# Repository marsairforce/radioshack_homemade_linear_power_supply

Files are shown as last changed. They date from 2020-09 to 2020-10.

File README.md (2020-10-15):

# Vintage Adjustable Linear Power Supply

Updating and improving on a very early project I built.

* Partly because I want something to do more things - dual tracking adjustable regulated outputs.
* Partly because I wanted to see how far I have come in my design skills from 10 year old me.
* Partly because I am bored

 I have been wanting to get more into analog circuits, like op-amp circuits and amplifiers. Building these on breadboards has always been challenging for me because I have always had only one bench power supply.  I have a modern bench power supply, but it also only has one output on it.

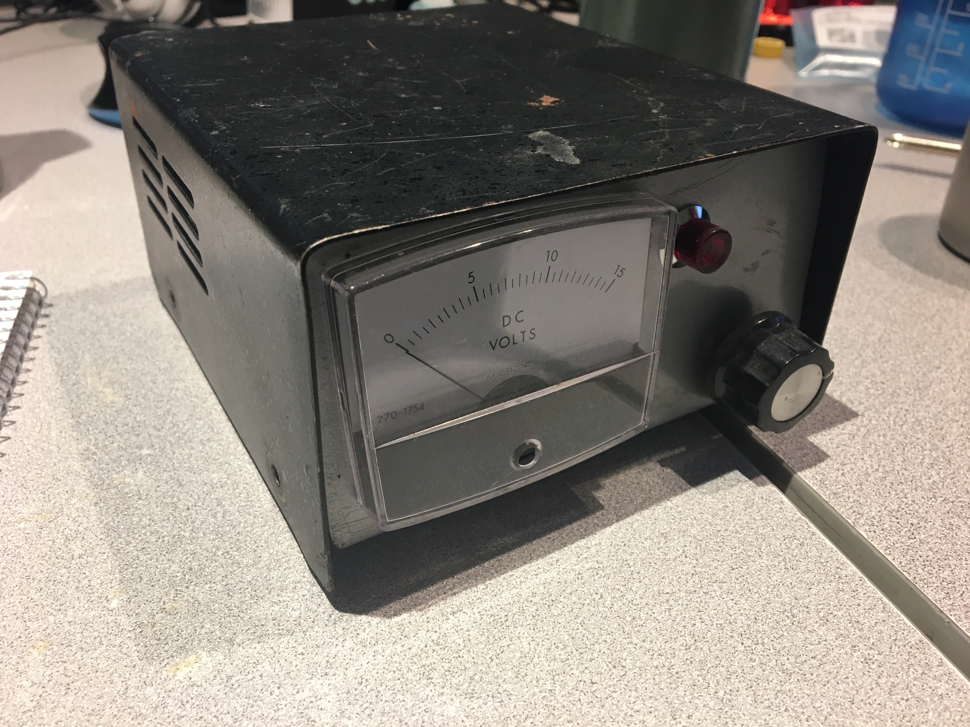
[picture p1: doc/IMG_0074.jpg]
old version together


## TL;DR

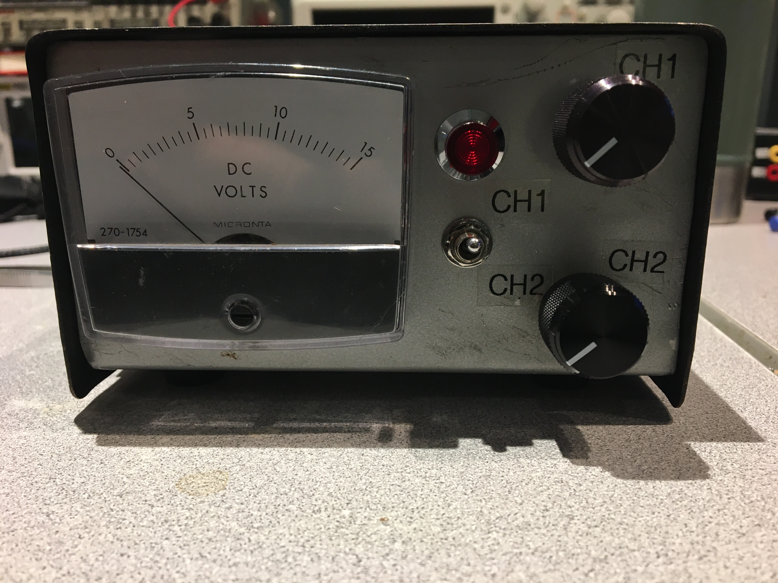
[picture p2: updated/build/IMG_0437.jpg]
front assembled


This is now a dual channel, double trackking voltage power supply.

Each channel can do about +/-1.2V to +/-20V at about 1A

## Analysis

I created this (I think) when I was in grade 4. So probably around 1987?

* Simple 317 regulator based adjustable power supply.

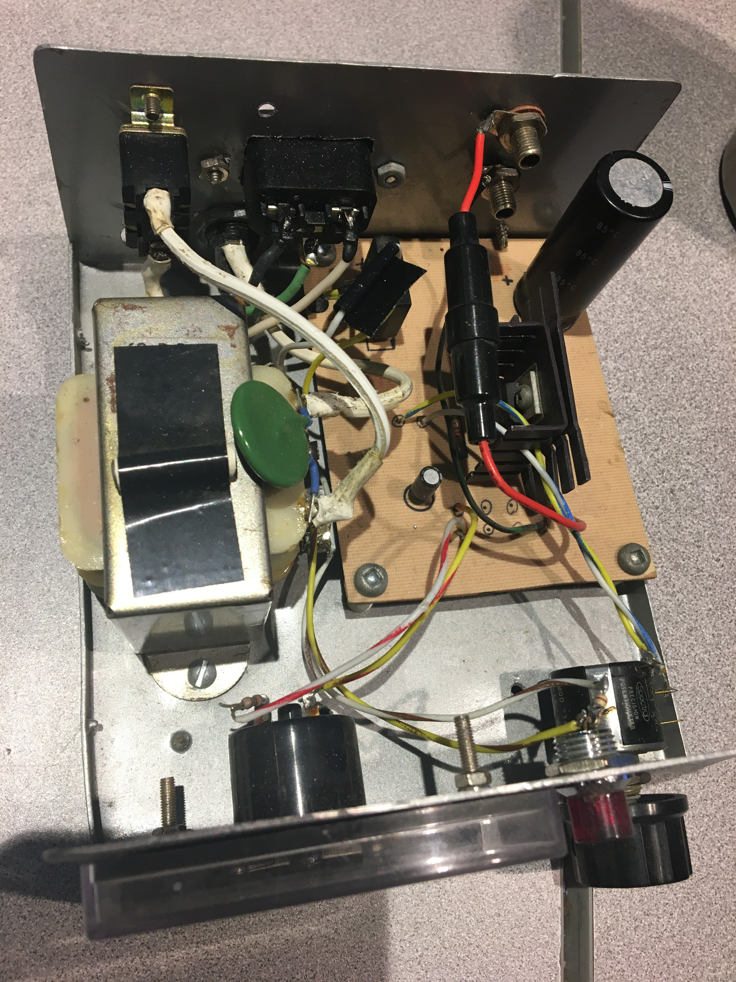
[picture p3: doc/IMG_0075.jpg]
inside


* Most components were baught from local Radio Shack store in St Vital mall.

  * Radio Shack project box.
  * 18V CT, 2A (36VA?) transformer.
  * Bridge Rectifier.
  * 2200uF capacitor
  * 317 volt regulator on free hanging heatsink.
  * Basic power connector, switch, fuze, with shitty heat shrink tubing on it.
  * Analog DC volt meter.
  * Indicator lamp, but bulb burnt out so I replaced it at some time with a LED stuffed into the lamp holder.
  * A pointless inline fuse holder, with a 2A fuse. This never would blow because the thing can only source 1A
  * Adjustable voltage knob - I remember getting this multi turn potentiometer from Active Electronics.
  * Custom etched single sided PCB
  * Serrible banana plug jacks.
  * Board standoffs (Active Electronics - I still have these) with stove bolts from hardware store.

I would like to say "I have come a long way since then". But at the same time, not really.

* I don't have a convenient way to make circuit boards at home any more.

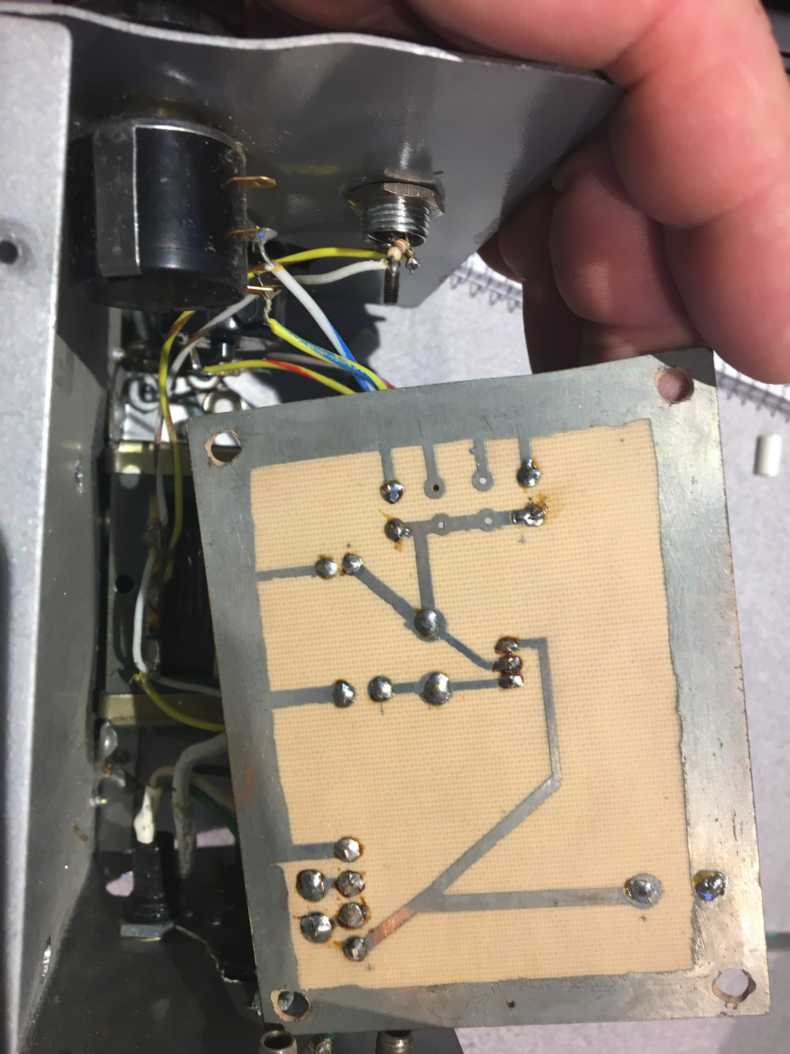
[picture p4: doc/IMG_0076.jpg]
pcb


This gem was hand drawn with a sharpie and then using a liquid tin to protect the copper.

In hindsight this is a terrible board layout.

* I still do not have good nuts and bolts hardware to mount circuit boards.

I have learned or improved a little bit more since I built this:

* I do have much better selection of wires now.

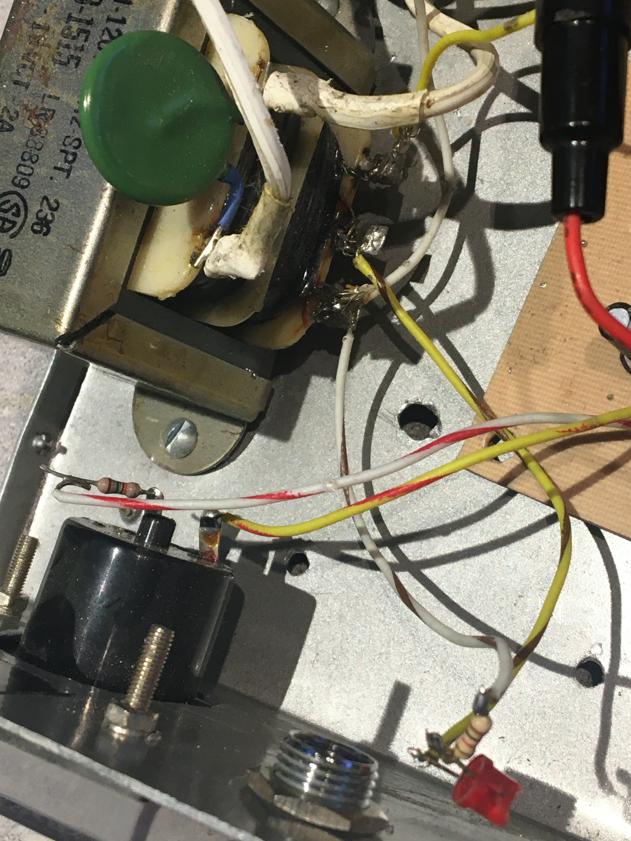
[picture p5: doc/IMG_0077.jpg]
old wires


* My soldering skills are a lot better. This thing looks like a Halloween house of horrors.

## Original Schematic

I created this in Kicad

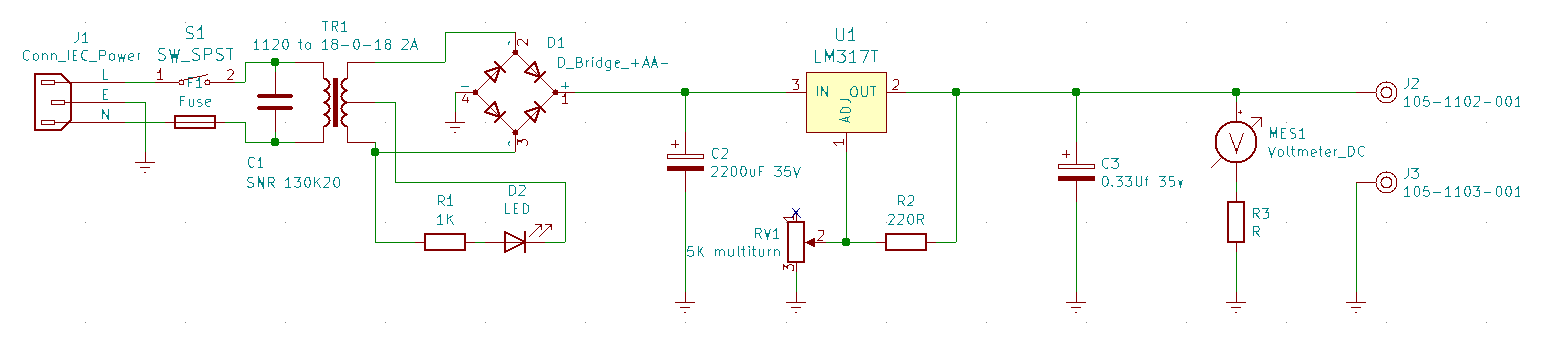
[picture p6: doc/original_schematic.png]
original schematic


This still functioned very well.

Funny notes as I was taking the old circuit apart.

* The C1 makes no sense. Why did I think I needed to have a ac line capacitor here? I probably had these and copied what I saw in other power supplies.
* The F1 should be after the switch on the hot side.
* The wires from J1, S1, T1 were a white lamp cord. I remember having this and using it for everything.
* The wires from T1 to the circuit board and everywhere else were from an old datacom cable I salvaged from one of my dad's construction sites. I stripped the cable jacket and used the wires for projects.
* I made a PCB using the kit from RadioShack. It is horrible layout and terrible pattern. But I did it with a sharpie and I was 8.
* The J2 was a metal not insulated binding post. As a kid I converted it into an insulated binding post by placing a piece of plastic drinking straw around the metal screw part of the  between the connector and the chassis. Somehow it continued to work all these years.

## Improvements

As usual I can't leave anything alone. Nothing is ever truly completed is it.

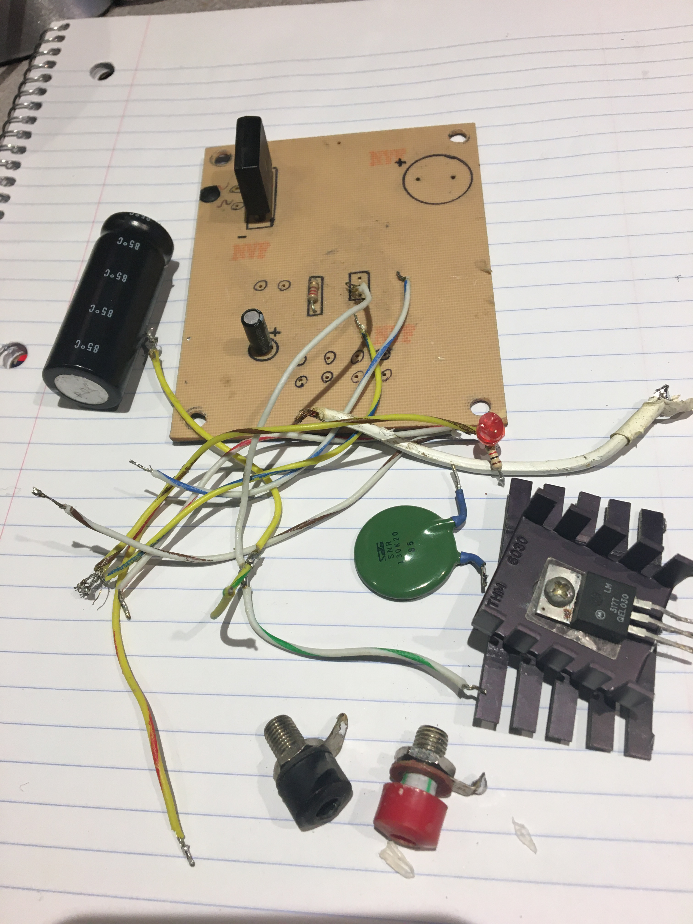
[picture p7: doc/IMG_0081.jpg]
taken apart


I ripped apart the old circuit and removed the parts from the chassis.  The front panel and bottom was a bit bent up from this being knocked around in storage I guess.

### Support more current output

* [Researching](https://www.homemade-circuits.com/lm317-with-outboard-current-boost/) adding a transistor to boost the current handling.

* https://www.ti.com/lit/ds/slvs044x/slvs044x.pdf

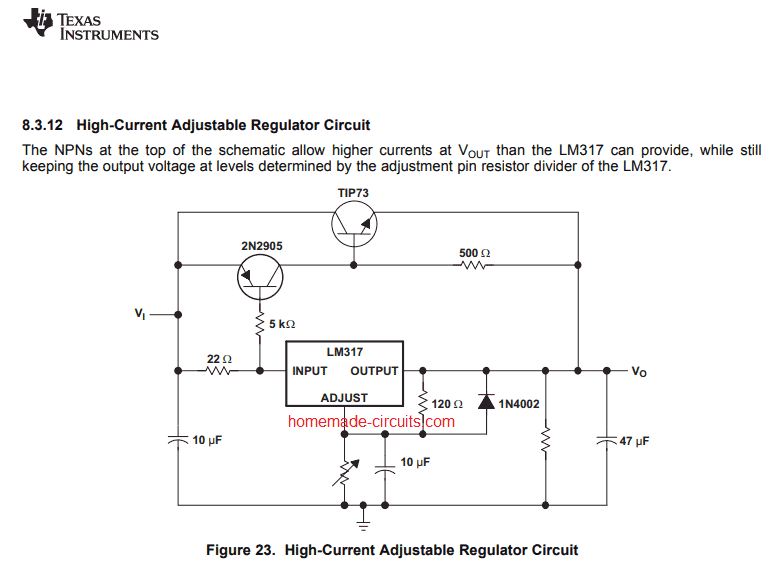
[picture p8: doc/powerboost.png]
circuit


This is fun. But I think this is too complicated. And the parts and heatsinks will take up too much space in this small chassis.

And considering the power transformer here is very small, I would be able to fully use this.

Instead, let's just use a [LD1085D2T-R‎](https://www.digikey.ca/product-detail/en/LD1085D2T-R/497-3424-1-ND/669200/?itemSeq=339103460). This has a power capacity of 3A.  And being a surface mount device I can use the PCB as the heatsink.

## More voltage outputs

I think having a single output is kind of useless for me.

* To build a variable output. But to build it as a [dual tracking control](https://www.youtube.com/watch?v=AOIxS7iOxbU). This is pretty neat. But the devil in the details of the op-amp needs a +/- power supply.

* A +/-15V supply for op-amps.

> HEY!!  I had "build a nice bench top op-amp power supply as one of my active projects.  I never got it out of design phase though. But what if I just build it into this existing power supply chassis I alredy have.  That seems practical to me too.

The dual tracking adjustable supply is neat as I do not have this with my existing bench top power supplies.

I think it is going to be challenging to fit all this stuff into this small chassis.

I compromised and designed a dual output dual tracking power supply. This gives me two channels of adjustable +/- voltage.

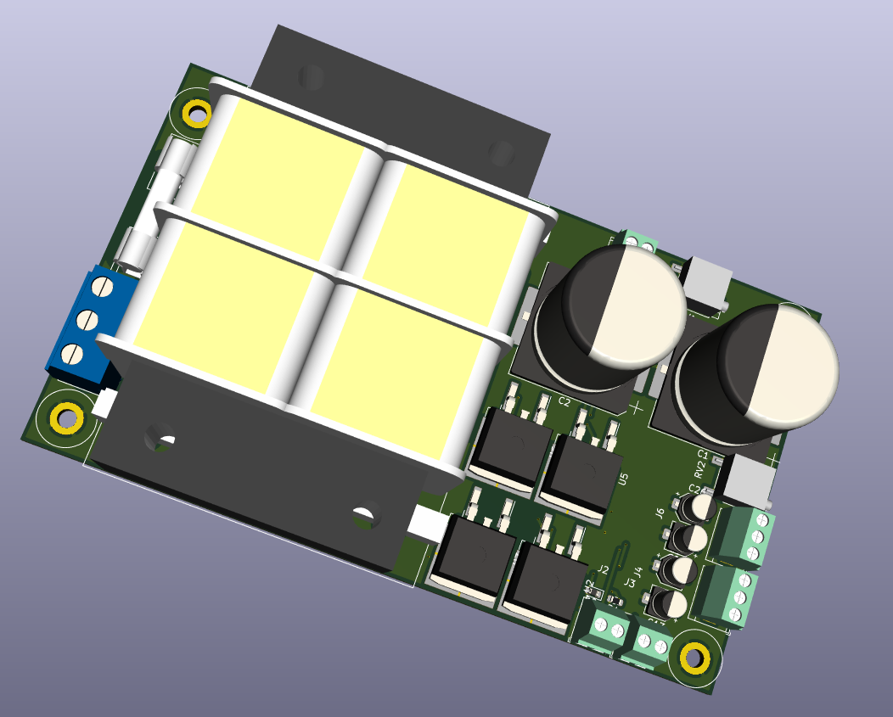
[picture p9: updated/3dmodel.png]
3dmodel


Each channel allows the use of a trimmer pot on the pcb, so it can practically behave as a fixed voltage.

I think I will go with having one channel be variable from the front panel and the other to be set with a trimmer.

## Updated schematic

This is in the updated folder, opamp_power_supply sub folder.

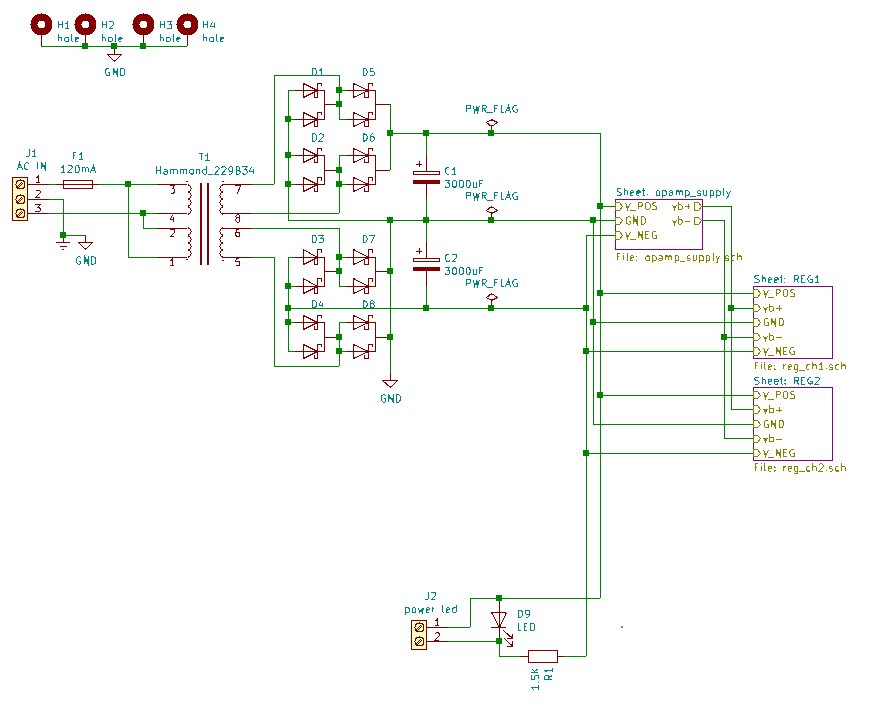
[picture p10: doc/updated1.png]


I started off with this Hammoond 229B34. It is a nice 12VA low profile transformer. It is semi-toroidial, so it has ok magnetic shielding as well. I was looking for something that had low electrical and magnetic noise. The original idea was to create a power supply suitable for powering audio op-amp circuits.

The configuration of this transformer lends itself to being able to use the secondary in series or in parallel.  In this case the secondary series voltage was about 38V. I don't need a power supply to go that high, so most of the voltage would be disapated as heat.
using the transformer secondary in parallel gives about 18V and about 600ma current output. But then is only single supply.
The approach here where I use them as separate secondaries is somewhere in between. I have an ok voltage to supply the regulators and a bit more or basically the same current than if i used the secondary in series.  I just need to use more diodes.  Fortunately diodes are cheap.

I chose to use Shotkey diodes here instead of regular rectifier diodes, because they have a lower forward voltage drop. Which means less energy gets lost as heat. These looke like they were diode arrays for use in the secondary of a switch mode power supply. Where you would want two dioded connected together, as for a full wave rectifier with the center tap right. But here I just use them in parallel. Because it helps further with the forward voltage losses. And I have them in the package for free. I could get a single diode in a DPAK pacakge. But these were pretty cheap as well.

I wanted rediculous large filter capacitors. There are some formulas I keep finding to calculate the capacitor size for the ripple voltage under an expected load. So I tried to use those. But then when you use regulators these all go askew anyway. The regulators specify they need a minimum of a relatively small capacitance. So these are going to be more than enough anyway. Again, wanting to have the perfect smooth DC supply for use in audio quality op-amp circuits.

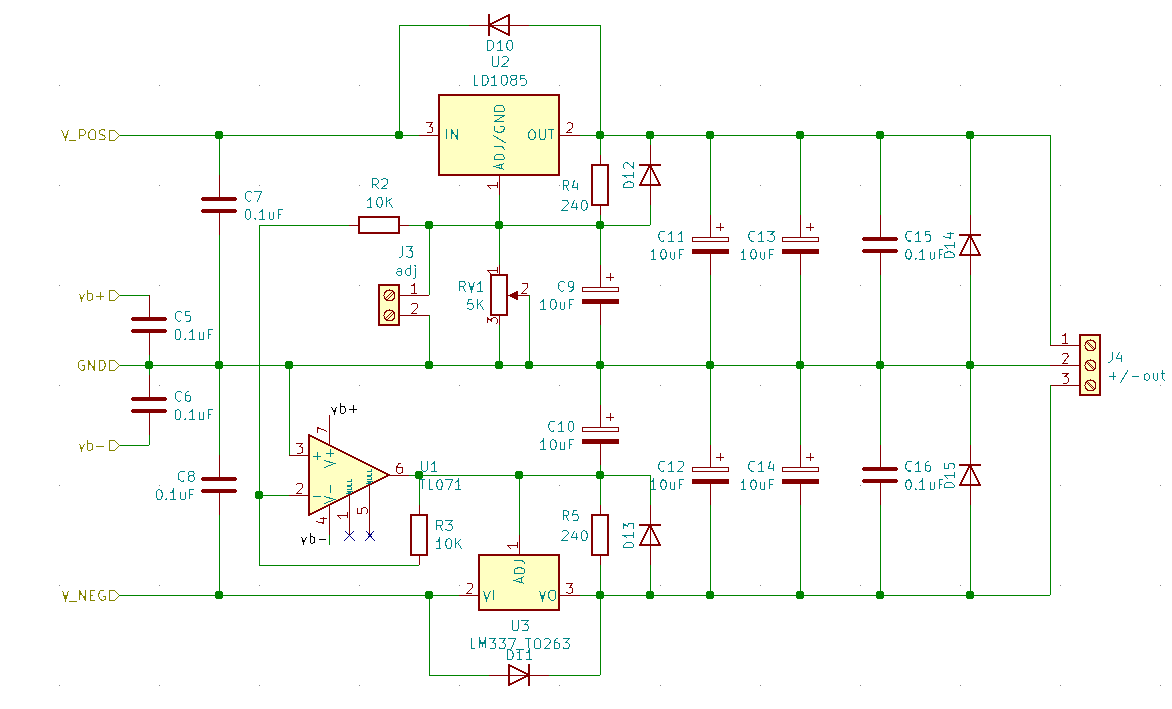
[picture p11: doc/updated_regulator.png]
updated regulator


Each channel a pair of regulators. These are the 317 and 337 adjustable family of regulators.

And then the op-amp there to provide the inverted voltage reference to the negative regulator. This allows for a single control voltage from one adjustable resistor to have both regulators adjust at the same time.

And then more filtering after the regulation. I have ceramic and electrolytic capacitors to help with transients.

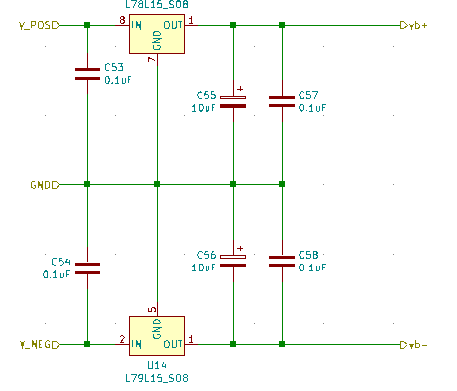
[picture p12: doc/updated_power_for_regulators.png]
regulator power supply


Of course the devil is in the details.

This op-amp requires its own +/-15V power supply.  But we are already building a power supply. And these are adjustable outputs at that.

So I added a small current +/-15V regulators here. These are smlal so-8 packages that are good for up to about 100mA. The op-amps I have here use much less than that.  I do not expose this supply as an output to be used off the power supply. Though I guess I could have. I didn't want this internal power that is used to control the regulators to be compromised by loading or shorting it out.

## PCB

I ordered the PCB from



It arrived a few weeks later.

I had the parts all ready to go. I ordered enough to build 3 modules. Because I pay for and get 3 boards anyway!. Sometimes that is a nuissance. But sometimes you can use it as a feature like this I guess.

I plan to build one into this power supply, to build a stand-alone op-amp power supply in a box. Where I set the outputs to +/-15V and +/-12V. And to have another one for use in a tube amplifier project idea I am still designing.

## Assembly

I built all three boards at the same time. At each step where I could I did some testing to make sure it was working.

* The transformer, fuze, and input connector, rectifier diodes - able to see rectified DC ripples on the filter capacitor pads.
* The capacitors - able to see DC voltage
* The 15V regulators - able to measure +/-15V
* The capacitors and resistors - bulk components. Test for continuity.
* The regulators - measure and test adjusting the voltage.

Put the board on some standoffs and mount it into the chassis

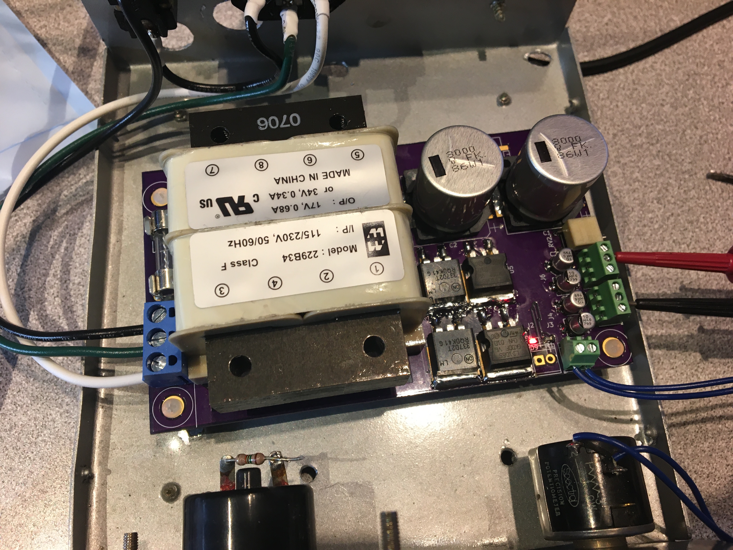
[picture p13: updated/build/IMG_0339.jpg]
board mounted


I didn't think about the potentiometers. I was just going to use the one I had from before. But when I was putting the new power supply PCB into the case I discovered it is not working very well. It feels all loose. I probably dropped this at some time and broke it. It still works but is very jittery when you turn it.

Time to replace this.

Since I am replacing it anyway and I do have space to add another potentiometer for the second channel I might as well do that now.

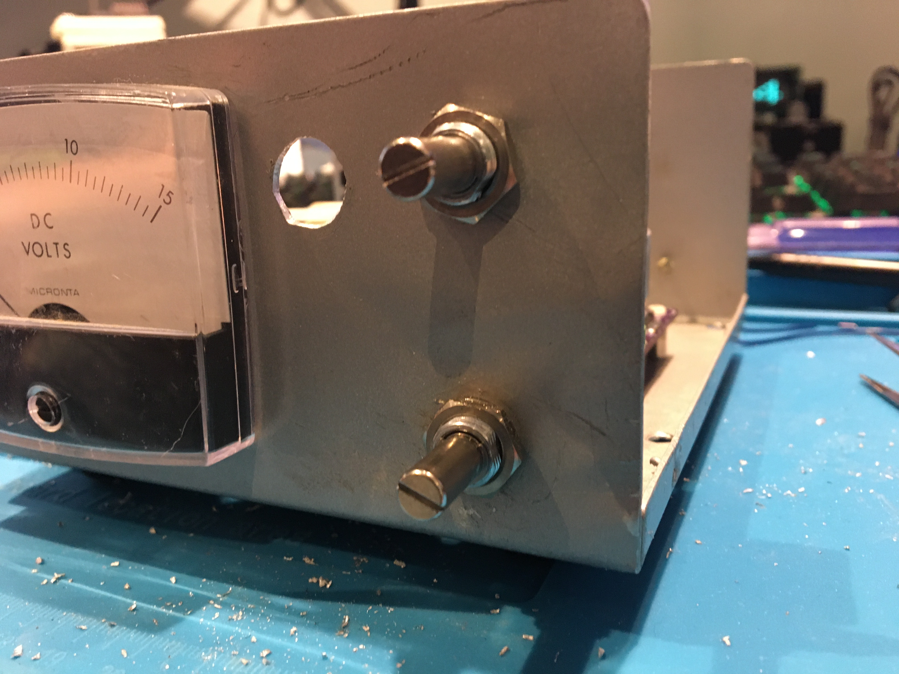
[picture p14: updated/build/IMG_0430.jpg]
knobs


And get some nice knobs for this. I am tired of the classic single knob I have had forever.

I will need some more output connectors on the back. Drill in some new holes and mount the connectors.

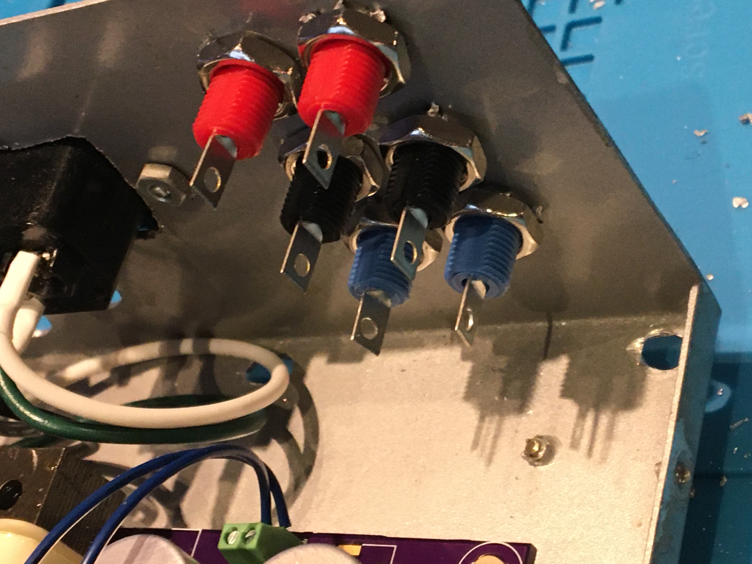
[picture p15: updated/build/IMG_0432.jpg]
new connectors


And then wire up the connectors to the screw terminals on the PCB.

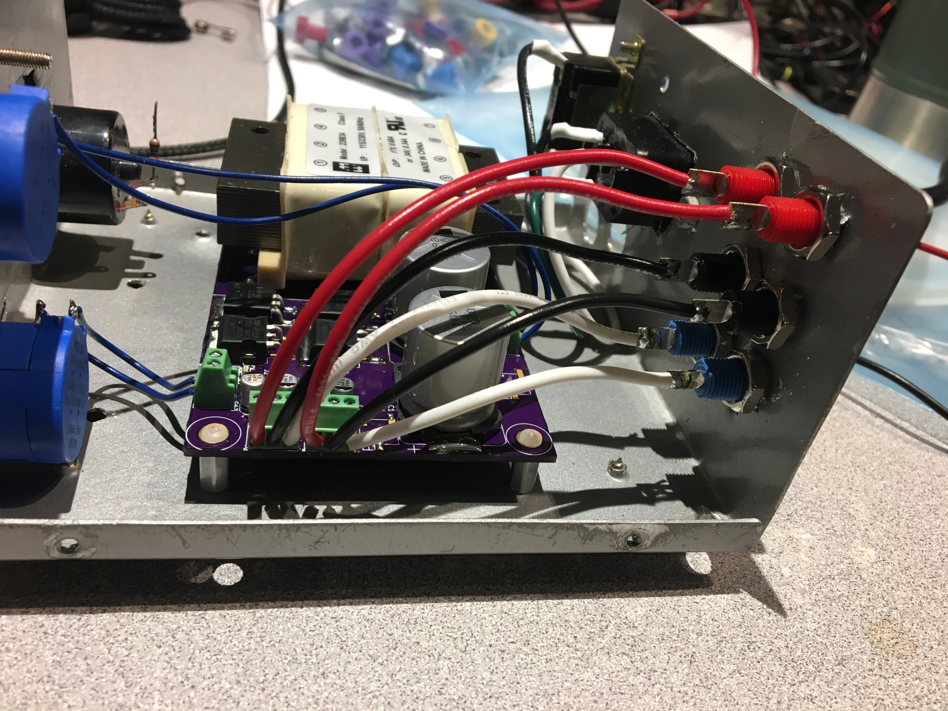
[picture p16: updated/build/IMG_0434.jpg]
wired connectors


Hook up the meter.

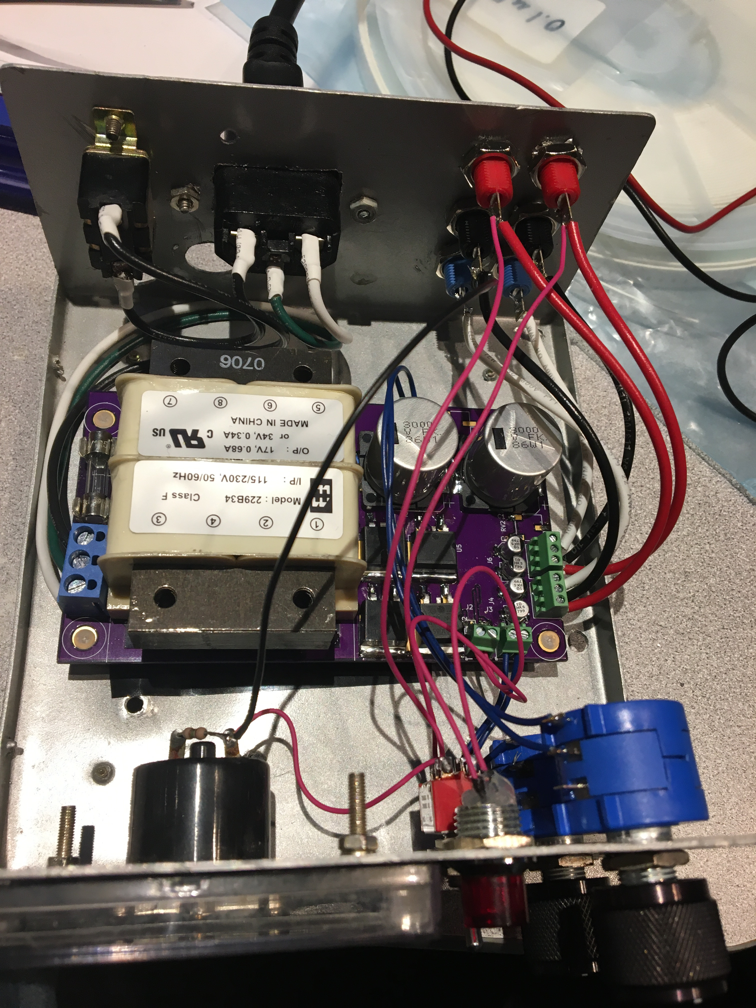
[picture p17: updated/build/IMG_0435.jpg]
meter wires


I only bother tracking the positive voltage, since the negative will track what ever the positive is but be opposite polarity right.

I added a toggle switch beside the meter so I can switch which channel is currently being displayed on the meter.

Fix the indicator LED and put it back together.
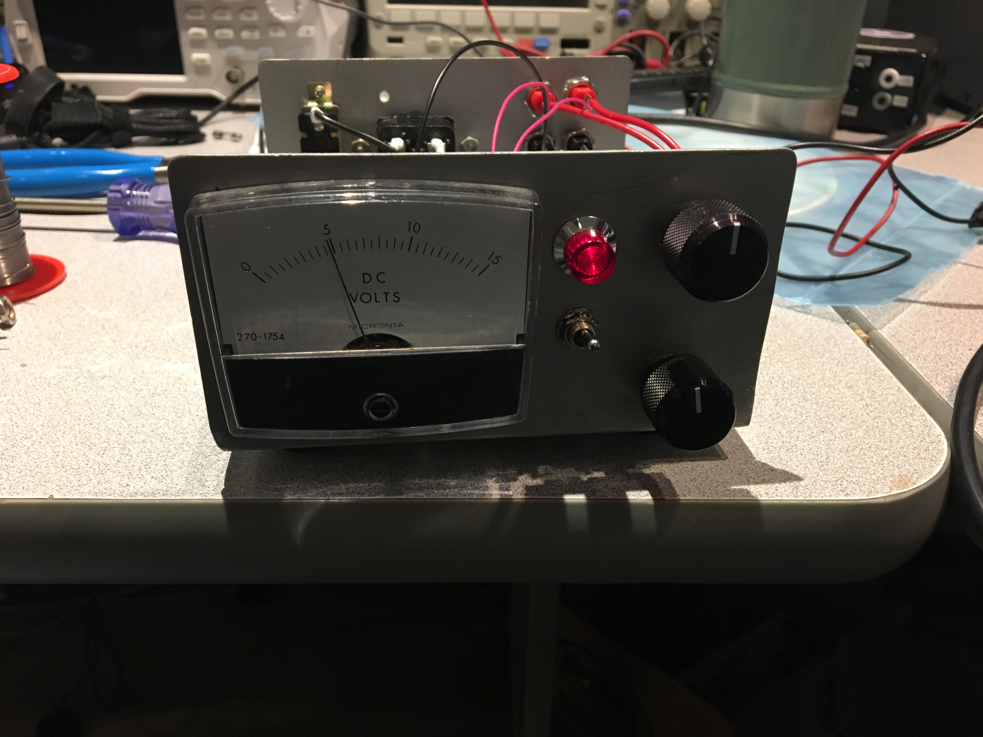
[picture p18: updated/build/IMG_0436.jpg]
indicator


A little bit of label maker ties it all together.

front assembled

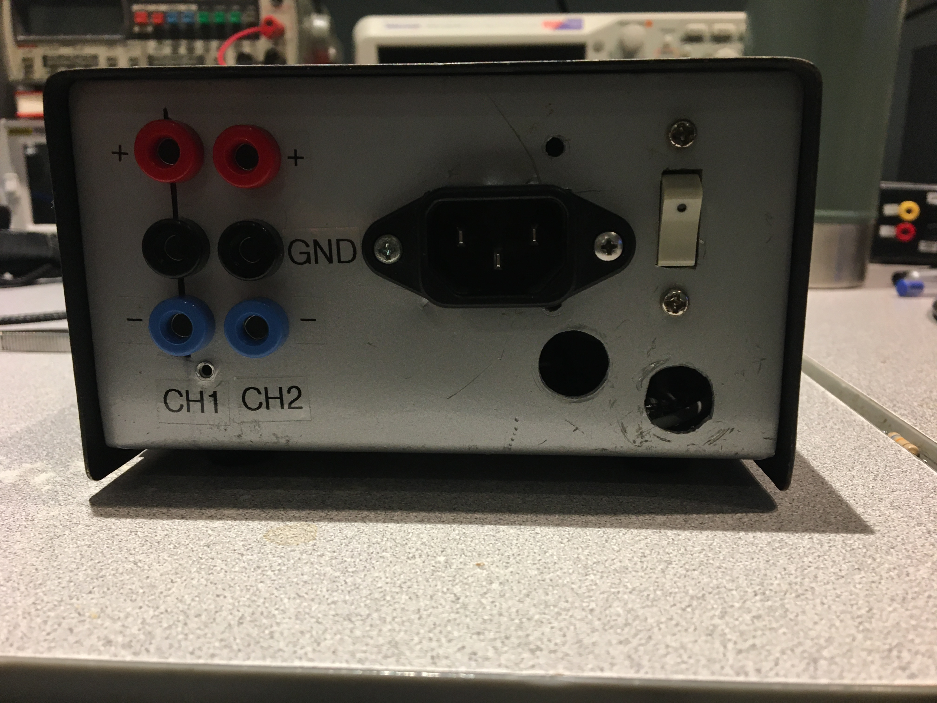
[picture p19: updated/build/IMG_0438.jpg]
rear assembled


Ready to roll.

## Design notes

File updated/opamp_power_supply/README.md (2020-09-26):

# A dual rail power supply for use in op-amp circuits

It keeps coming up where I need to get a good dual rail op-amp power supply in projects.

Wanting to design a power supply module that is economical and small form factor and general purpose enough to be put into various applications as needed.

## Requirements

* Input from 120VAC
* IEC power connector, fuze. Optional switch.
* +15V and -15V outputs. Perhaps up to 1A is all we would need.
* A +5V output for other logic circuits in the project.

## Nice to have

* Efficient. Not using linear regulators. It would be quite readily available to use a transformer, a 7815, 7915 regulators, capacitors. But transformers tend to be expensive.
* Small. Not using large bulky and expensive transformer.
* Low noise. Suitable for use in audio applications.

## Investigation

It turns out What I am looking for just exists as a module: https://www.digikey.ca/product-detail/en/xp-power/ECL15UT03-E/1470-1185-ND/4487566 $80

Done.

No project to do at this time.

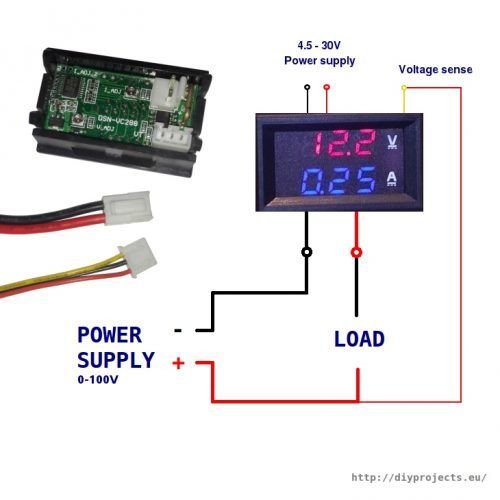
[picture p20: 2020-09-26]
doc/volt-amp-display.jpg

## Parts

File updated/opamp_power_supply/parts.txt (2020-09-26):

1 J152-ND‎         CONN BANANA JACK SLDR TABS BLACK
1 ‎J151-ND‎         CONN BANANA JACK SOLDER TABS RED
1 ‎237-1341-ND‎     PWR XFMR TORO 100VA CHAS MT

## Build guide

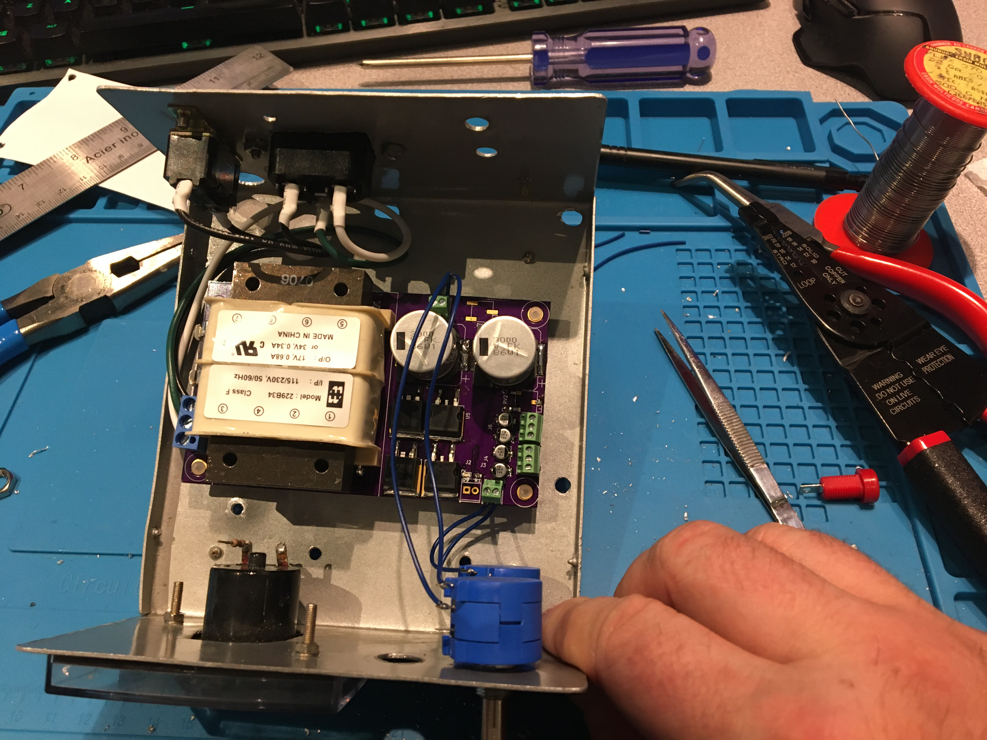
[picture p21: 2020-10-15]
updated/build/IMG_0431.jpg

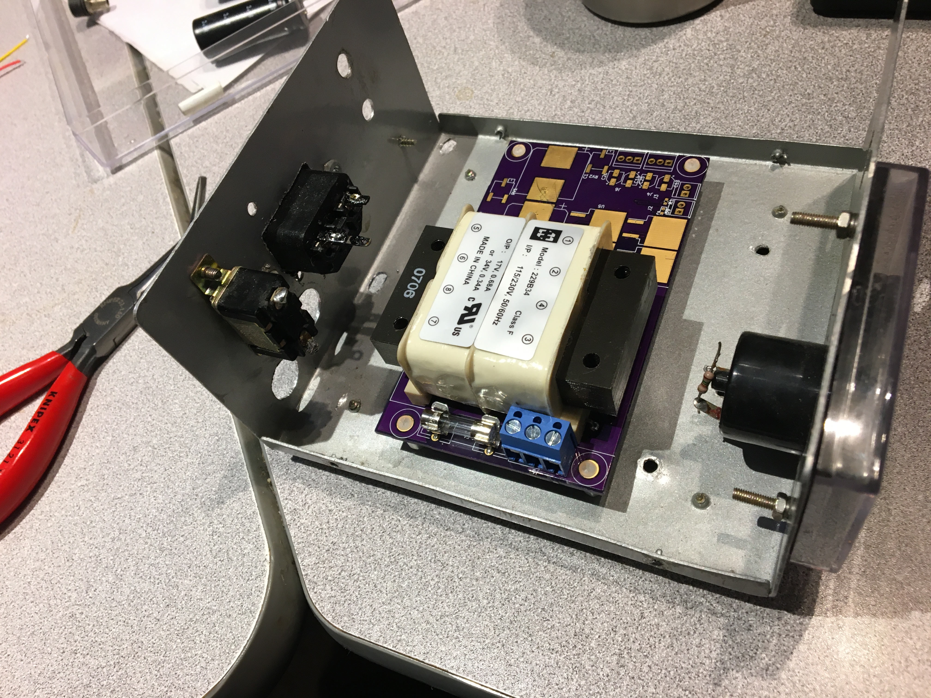
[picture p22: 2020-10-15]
updated/build/IMG_0308.jpg

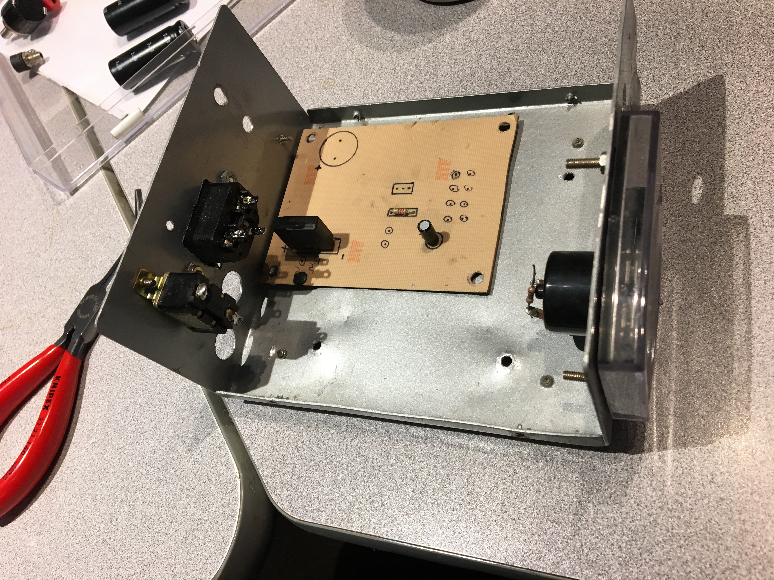
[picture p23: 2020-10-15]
updated/build/IMG_0307.jpg

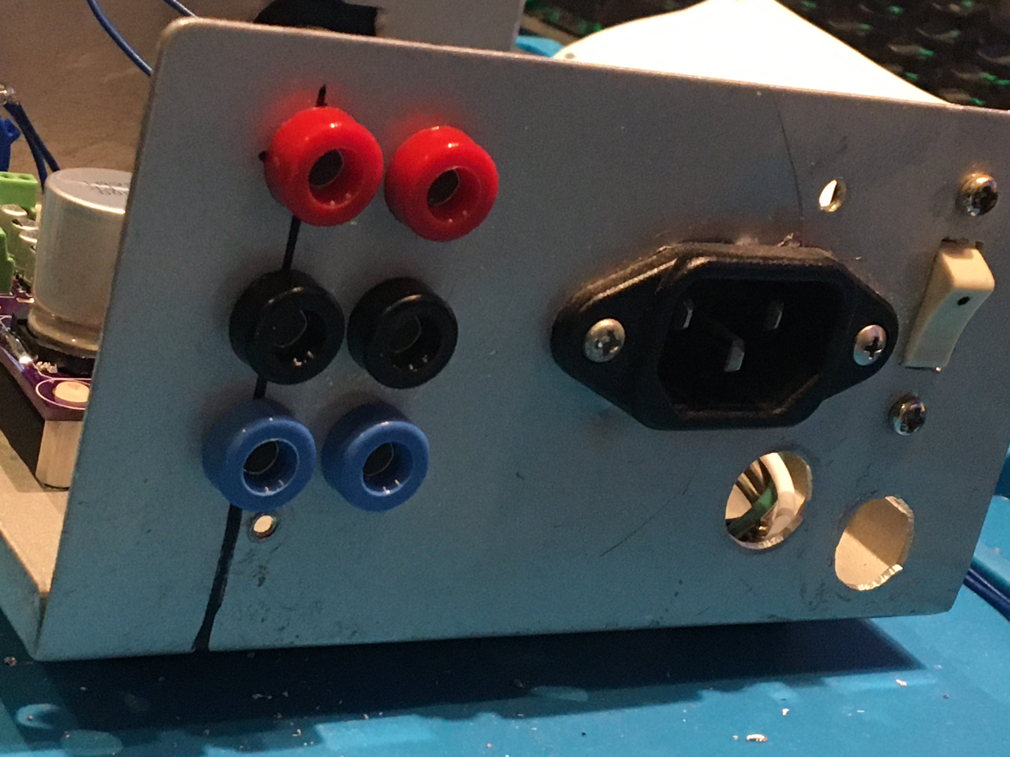
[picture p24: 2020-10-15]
updated/build/IMG_0433.jpg

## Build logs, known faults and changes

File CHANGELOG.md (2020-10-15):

# Change log

## 2020-10-15

The knobs I needed arrived today. Can finish assembling the power supply.

* Mount the PCB by drilling holes.
* Make new hole for the 2nd channel adjust knob on the front.
* Make new holes for output connectors on the back.
* Wire up the output connectors using 22ga wire. Wanting to not have a voltage drop from wires inside the power supply.
* Install the 1A fuse now that I have it.
* Drill in a new toggle switch to control which output the meter will display.
* Remove LED power indicator from the board and install an LED on wire to screw terminal. Use the old incandescant bulb socket for the look.
* Use a label maker to add labels to everything.

The power supply is back together now.

Test the loading of the power supply

Set CH1 to 3.2V (which will be +/- 6.3V right). Using both regulators here for the channel then.
Try to run a filament of a 6l6GC tube. It wants to draw 1.2A. I am able to power it for a few seconds but then the power supply looks like it goes into shutdown mode. Probably thermal conditions on the board.

I seem to be able to draw 400mA of power by powering filaments of a 12AX7 tubes.

Use a probe on the scope with AC coupling. I am not able to see any ripple.

Excellent. Going to put this back together.

## 2020-10-08

The PCB arrived in the mail from OSHPark.

Spend all evening assembling them.  There were 3 PCB. I had components to assemble all 3 of them.

I took some time to test them as I was assembling them.

* just the transformer
* add the rectifier diodes
* add filter caps
* add internal regulators for op-amps
* add regulators and caps

So far it appears all three modules work as expected.

I am close to being able to assemble this into the case.
But the single 5k multi turn pot I had is broken. I did not think about that. It is very loose and jittery. Going to replace it with a new one.

And at this time my idea is to get two pots and put a toggle switch onto the bezel in the hole where the indicator light was, so that I can use this to switch the meter to display the voltage on each channel. Having two adjustable outputs is better than having one adjustable output.

But it bothers me that I did not think about the adjustment knob before. And that I need to make yet another Digi-Key order to get these. And it is Friday before a long weekend now. This will have to wait again until next week.

## 2020-09-22

Have the idea that I should have the option to use a variable resistor on board, as well as a screw terminal, for both channels on the power supply. Before I had this set up as one with just a screw terminal and one with just a 5K pot. Add footprints so I can populate them for both channels if I want to.
The use case to have the power supply work as a fixed dual channel regulator, or to have two adjustment knobs right.
I will have 3 of these boards, so I might as well populate all of them with components and get them packagd into projects to use them.

## 2020-09-21

Did a PCB layout of the transformer I was using for the op-amp power supply. Changed the fixed +/-15V regulators for adjustable ones, and added dual tracking op-amp to control negative regulator from positive adjust.
The board is about 120.5 x 82.6mm. And I needed to use 4 layer board because of the tight packing here. This will cost about $154.20 USD to get this board made.
This is not ideal. The size is most of the space inside this old chassis. I don't think I would be able to fit it in when I have the power connectors, adjustment knob, output connectors, and the panel meter. Also the PCB is just too expensive for what that is.

Need to re-think making it smaller.

* use less regulators, so less output channels.
* Separate the transformer from the regulators. Just make small regulator boards per channel.  - no . then I need two boards.
* Order a 120V to 24V switching power supply from aliexpress. This thing was only $30. And is 106x98.2mm, a good fit inside this chassis. - no. because then I need a way to recover negative supply rail. I want a dual tracking power supply here.

I cut the outputs from 4 pairs down to 2. That is sill Ok. I guess. Its more likely I won't even use them all anyway. Given this is a small 12VA transformer it would not be very powerful for like tube fillaments i guess anyway.

And. I have a sweet dual rail 15V supply for op amps. that is adjustable, but will be set by internal vAdj screw inside the power supply. And then the chassis mounted multi turn knob to control the oher channel pair of regulars conveniently.

Get the board redesigned to use a 2 layer PCB, and at dimensions small enough so it is only $50 USD to make. Much better.
Go ahead and place a Digi-Key order for the parts I need to populate the board. I want to test fit all the footprints before I send the board off to make, as I am expecting I have made an error in footprint sizes. I always do.

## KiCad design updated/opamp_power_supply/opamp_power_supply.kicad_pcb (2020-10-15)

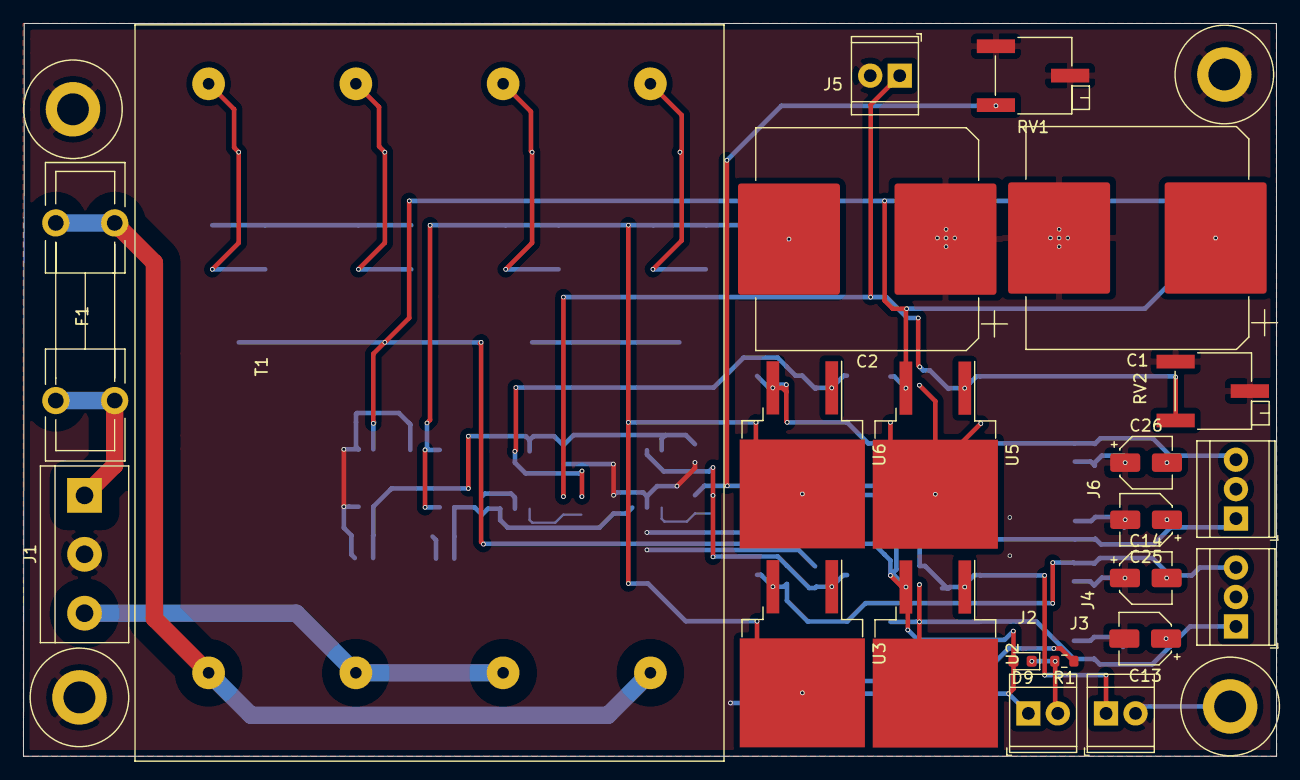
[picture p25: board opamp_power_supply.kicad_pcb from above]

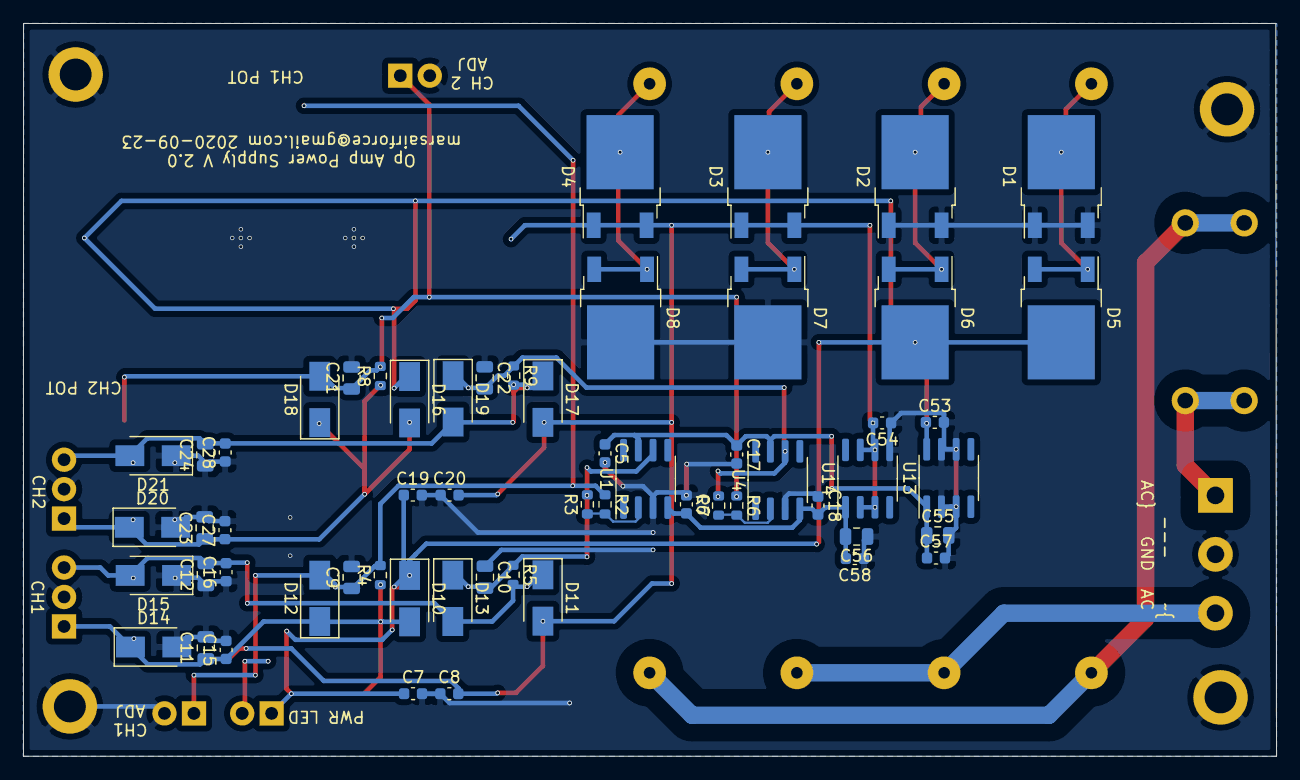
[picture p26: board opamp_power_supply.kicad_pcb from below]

Board: 2 copper layers, 108.1 x 63.2 mm, 84 parts (58 on the bottom side), 23 nets.

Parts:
C1, C2: 3000uF; CP_Elec_18x22
C5, C6, C7, C8, C15, C16, C17, C18, C19, C20, C27, C28, C53, C54, C57, C58: 0.1uF; C_0603_1608Metric
C9, C10, C11, C12, C21, C22, C23, C24, C55, C56: 10uF; C_0805_2012Metric
C13, C14, C25, C26: 10uF; CP_Elec_4x5.8
D1, D2, D3, D4, D5, D6, D7, D8: MBRD6100CTTR; TO-252-2
D9: LED; D_0603_1608Metric
D10, D11, D12, D13, D14, D15, D16, D17, D18, D19, D20, D21: S1M-13-F; D_SMA
F1: 120mA; Fuseholder5x20_horiz_open_lateral_Type-II
H1, H2, H3, H4: hole; Mounting_Hole_Plated_M2.5
J1: AC IN; TerminalBlock-3_P5.08mm
J2: power led; TerminalBlock_1x02_P2.54mm_Horizontal
J3, J5: adj; TerminalBlock_1x02_P2.54mm_Horizontal
J4, J6: +/-out; TerminalBlock_1x03_P2.54mm_Horizontal
R1: 1.5K; R_0603_1608Metric
R2, R3, R6, R7: 10K; R_0603_1608Metric
R4, R5, R8, R9: 240; R_0603_1608Metric
RV1, RV2: 5K; Potentiometer_Bourns_3269P_Horizontal
T1: Hammond_229B34; Hammond_229_series_low_profile_transformers
U1, U4: TL071; SOIC-8_3.9x4.9mm_P1.27mm
U2, U5: LD1085; TO-263-2
U3, U6: LM337_TO263; TO-263-2
U13: L78L15_SO8; SOIC-8_3.9x4.9mm_P1.27mm
U14: L79L15_SO8; SOIC-8_3.9x4.9mm_P1.27mm

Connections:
/REG1/V_NEG: C2.2, C8.2, C20.2, C54.2, D3.1, D3.3, D4.1, D4.3, D11.2, D17.2, R1.1, U3.2, U6.2, U14.2, U14.3, U14.6, U14.7
/REG1/V_POS: C1.1, C7.1, C19.1, C53.1, D5.2, D6.2, D9.2, D10.1, D16.1, J2.1, U2.3, U5.3, U13.8
/REG1/vb+: C5.1, C17.1, C55.1, C57.1, U1.7, U4.7, U13.1
/REG1/vb-: C6.2, C18.2, C56.2, C58.2, U1.4, U4.4, U14.1
Earth: C1.2, C2.1, C5.2, C6.1, C7.2, C8.1, C9.2, C10.1, C11.2, C12.1, C13.2, C14.1, C15.2, C16.1, C17.2, C18.1, C19.2, C20.1, C21.2, C22.1, C23.2, C24.1, C25.2, C26.1, C27.2, C28.1, C53.2, C54.1, C55.2, C56.1, C57.2, C58.1, D1.1, D1.3, D2.1, D2.3, D7.2, D8.2, D14.2, D15.1, D20.2, D21.1, H1.1, H2.1, H3.1, H4.1, J1.2, J3.2, J4.2, J5.2, J6.2, RV1.2, RV1.3, RV2.2, RV2.3, U1.3, U4.3, U13.2, U13.3, U13.6, U13.7, U14.5
unnamed: C9.1, D12.2, J3.1, R2.1, R4.2, RV1.1, U2.1
unnamed: C10.2, D13.1, R3.2, R5.1, U1.6, U3.1
unnamed: C11.1, C13.1, C15.1, D10.2, D12.1, D14.1, J4.1, R4.1, U2.2
unnamed: C12.2, C14.2, C16.2, D11.1, D13.2, D15.2, J4.3, R5.2, U3.3
unnamed: C21.1, D18.2, J5.1, R6.1, R8.2, RV2.1, U5.1
unnamed: C22.2, D19.1, R7.2, R9.1, U4.6, U6.1
unnamed: C23.1, C25.1, C27.1, D16.2, D18.1, D20.1, J6.1, R8.1, U5.2
unnamed: C24.2, C26.2, C28.2, D17.1, D19.2, D21.2, J6.3, R9.2, U6.3
unnamed: D1.2, D5.1, D5.3, T1.7
unnamed: D2.2, D6.1, D6.3, T1.8
unnamed: D3.2, D7.1, D7.3, T1.6
unnamed: D4.2, D8.1, D8.3, T1.5
unnamed: D9.1, J2.2, R1.2
unnamed: F1.1, T1.1, T1.3
unnamed: F1.2, J1.1
unnamed: J1.3, T1.2, T1.4
unnamed: R2.2, R3.1, U1.2
unnamed: R6.2, R7.1, U4.2
